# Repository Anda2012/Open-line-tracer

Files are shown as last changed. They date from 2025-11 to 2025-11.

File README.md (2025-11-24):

**Open source MicroPython 11-Channel PID Line Follower**

ESP32-C3 Mini-1 + Massmore JET QTR-11D

This project is a compact and accurate line follower built with an ESP32-C3 Mini-1 running MicroPython and an 11-channel Massmore JET QTR-11D reflectance sensor. It reads all sensor channels, calculates line position, and applies a tunable PID controller to drive the motors smoothly.

 Features

11-channel reflectance sensing

PID control (P, I, D adjustable in code)

Smooth PWM motor output

Simple, modular MicroPython code

Works with the DRV8833 motor driver

uses the ip5306 battery charger & boost converter

 **Project Structure**
src
 │ main.py         Main loop + motor control
 │ config.py       PID + speed settings

**Setup**

Install MicroPython on the ESP32-C3.

Upload the /src files to the board.

Adjust PID constants in config.py as needed.

Run main.py to start the line follower.

**PID Tuning Tips**

Increase P for stronger corrections.

Add I to reduce drift on long straights.

Use D to smooth out fast turns.

**License**

MIT License

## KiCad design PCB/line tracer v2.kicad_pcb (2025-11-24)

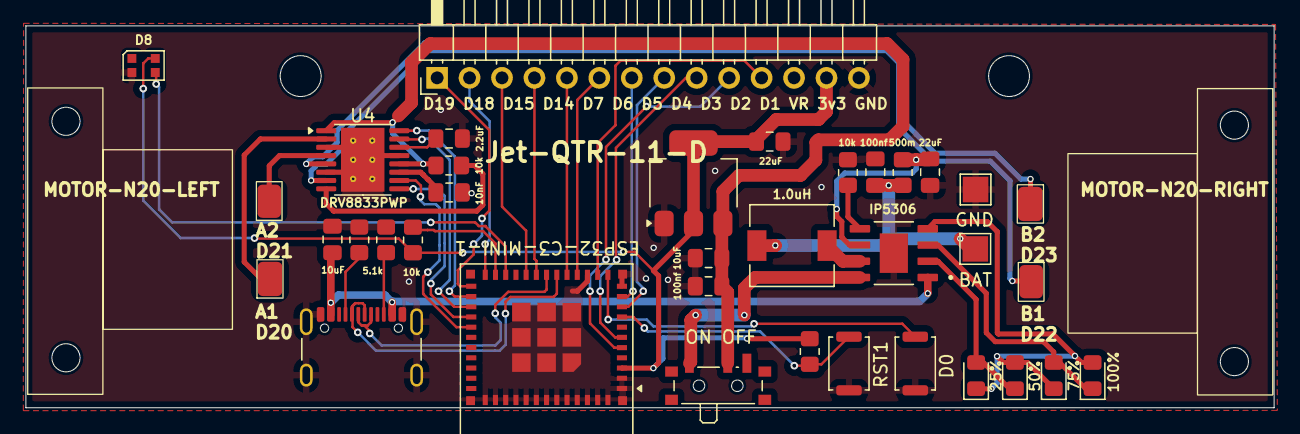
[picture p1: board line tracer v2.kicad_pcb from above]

Board: 2 copper layers, 97.7 x 29.9 mm, 34 parts (0 on the bottom side), 42 nets.

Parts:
BAT: TestPoint; TestPoint_Pad_2.0x2.0mm
C1, C2: 22uF; C_0805_2012Metric_Pad1.18x1.45mm_HandSolder
C3: 2.2uF; C_0805_2012Metric_Pad1.18x1.45mm_HandSolder
C4, C10: 10uF; C_0805_2012Metric_Pad1.18x1.45mm_HandSolder
C5, C6: 100nf; C_0805_2012Metric_Pad1.18x1.45mm_HandSolder
C8: 10nF; C_0805_2012Metric_Pad1.18x1.45mm_HandSolder
D0: SW_Push; SW_Push_SPST_NO_Alps_SKRK
D1: 25%; LED_0805_2012Metric_Pad1.15x1.40mm_HandSolder
D2: 50%; LED_0805_2012Metric_Pad1.15x1.40mm_HandSolder
D3: 75%; LED_0805_2012Metric_Pad1.15x1.40mm_HandSolder
D4: 100%; LED_0805_2012Metric_Pad1.15x1.40mm_HandSolder
D8: WS2812B-2020; LED_WS2812B-2020_PLCC4_2.0x2.0mm
GND: TestPoint; TestPoint_Pad_2.0x2.0mm
J1: USB_C_Receptacle_USB2.0_16P; USB_C_Receptacle_GCT_USB4105-xx-A_16P_TopMnt_Horizontal
L1: 1.0uH; L_6.3x6.3_H3
MA1: Motor_DC; N20 motor
MB1: Motor_DC; N20 motor
ON OFF: SW_Push_SPDT; SW_SPDT_PCM12
R1, R3: 5.1k; R_0805_2012Metric_Pad1.20x1.40mm_HandSolder
R2: 10K; R_0805_2012Metric_Pad1.20x1.40mm_HandSolder
R4, R6, R14: 10k; R_0805_2012Metric_Pad1.20x1.40mm_HandSolder
R7: 500m; R_0805_2012Metric_Pad1.20x1.40mm_HandSolder
RST1: SW_Push; SW_Push_SPST_NO_Alps_SKRK
U1: IP5306; ip5306
U2: AMS1117-3.3; SOT-223-3_TabPin2
U3: JET-QTR-11D; PinHeader_1x14_P2.54mm_Horizontal
U4: DRV8833PWP; HTSSOP-16-1EP_4.4x5mm_P0.65mm_EP3.4x5mm_Mask2.46x2.31mm_The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
U5: ESP32-C3-MINI-1; ESP32-C6-MINI-1

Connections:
5v bat: C4.1, C6.1, ON OFF.2 (B), R6.2, U2.3 (VI), U4.1 (~SLEEP), U4.12 (VM)
5v in: ON OFF.1 (A), U1.8 (VOUT)
+3V3: C2.1, D8.4 (VDD), R2.2, R14.1, U2.2 (VO), U3.13, U5.3 (3V3)
+5V: C10.1, J1.A4 (VBUS), J1.A9 (VBUS), J1.B4 (VBUS), J1.B9 (VBUS), U1.1 (VIN)
A1: U4.16 (AIN1), U5.26 (IO20)
A2: U4.15 (AIN2), U5.27 (IO21)
B1: U4.9 (BIN1), U5.28 (IO22)
B2: U4.10 (BIN2), U5.29 (IO23)
BAT: BAT.1, C5.1, L1.2, R7.1
D1: U3.11, U5.13 (IO1)
D2: U3.10, U5.5 (IO2)
D3: U3.9, U5.6 (IO3)
D4: U3.8, U5.9 (IO4)
D5: U3.7, U5.10 (IO5)
D6: U3.6, U5.15 (IO6)
D7: U3.5, U5.16 (IO7)
D14: U3.4, U5.19 (IO14)
D15: U3.3, U5.20 (IO15)
D18: U3.2, U5.24 (IO18)
D19: U3.1, U5.25 (IO19)
D+: J1.A6 (D+), J1.B6 (D+), U5.18 (IO13)
D-: J1.A7 (D-), J1.B7 (D-), U5.17 (IO12)
EN: R2.1, RST1.1, U5.8 (EN)
GND: C1.2, C2.2, C3.2, C4.2, C5.2, C6.2, C8.1, C10.2, D0.2, D8.2 (VSS), GND.1, J1.A1 (GND), J1.A12 (GND), J1.B1 (GND), J1.B12 (GND), J1.S1 (SHIELD), R1.2, R3.2, R4.1, RST1.2, U1.9 (POWERPAD), U2.1 (GND), U3.14, U4.3 (AISEN), U4.6 (BISEN), U4.13 (GND), U4.17 (GND), U5.1 (GND), U5.2 (GND), U5.11 (GND), U5.14 (GND), U5.36 (GND), U5.37 (GND), U5.38 (GND), U5.39 (GND), U5.40 (GND), U5.41 (GND), U5.42 (GND), U5.43 (GND), U5.44 (GND), U5.45 (GND), U5.46 (GND), U5.47 (GND), U5.48 (GND), U5.49 (GND), U5.50 (GND), U5.51 (GND), U5.52 (GND), U5.53 (GND)
IO0: D0.1, U5.12 (IO0)
N1A: MA1.1 (+), U4.2 (AOUT1)
N1B: MA1.2 (-), U4.4 (AOUT2)
N2A: MB1.2 (-), U4.7 (BOUT1)
N2B: MB1.1 (+), U4.5 (BOUT2)
unnamed: D1.2 (A), D2.1 (K), U1.2 (LED1)
unnamed: D1.1 (K), D2.2 (A), D3.1 (K), D4.2 (A), U1.4 (LED3)
unnamed: D3.2 (A), D4.1 (K), U1.3 (LED2)
unnamed: D8.3 (DIN), U5.22 (IO8)
unnamed: J1.A5 (CC1), R1.1
unnamed: J1.B5 (CC2), R3.1
unnamed: C1.1, R7.2, U1.6 (BAT)
unnamed: R4.2, U1.5 (KEY)
unnamed: L1.1, U1.7 (SW)
unnamed: C8.2, U4.11 (VCP)
unnamed: C3.1, U4.14 (VINT)
unnamed: R6.1, U4.8 (~FAULT)
unnamed: R14.2, U5.23 (IO9)
